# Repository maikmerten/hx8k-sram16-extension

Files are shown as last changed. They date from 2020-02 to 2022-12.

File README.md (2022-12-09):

# hx8k-sram16-extension
A PCB with 4 Mbit of SRAM,  SPI-Flash, two LEDs, a button, SPI-connectors, and a single-row pmod-compatible connector for the Lattice HX8K Breakout Board. Connects to the headers **J3** and **J4** on the Lattice HX8K Breakout Board.

## WARNING: unstable

The board in its current state is difficult to operate in a stable manner. While signals to the SRAM-chip appear to be of decent quality, I've yet to achieve stable operation over extended periods of operation. This might be a matter of my SRAM-controller design within the FPGA, or an issue with the board design available here. Please be aware of this before considering deploying this design in your projects.

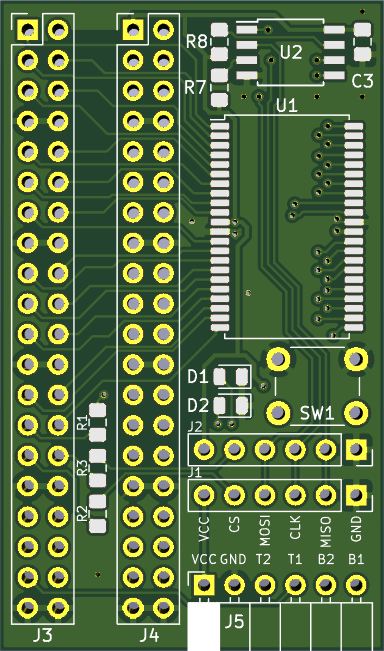
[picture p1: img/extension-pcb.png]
top side of the board top side


## BOM

| Component | Description | Qty. |
|---|---|---|
| U1 | 4 MBit SRAM chip, 256Kx16, e.g. AS7C34098A, 10ns or faster recommended, TSOP-II 44 package | 1 |
| U2 | SPI-Flash, e.g. W25Q32JV, 8-Pin SOIC package| 1 |
| C1, C2, C3 | 100nF ceramic capacitor, 0805 package | 3 |
| D1, D2 | SMD LEDs, red, 0805 package | 2 |
| R1, R2, R3, R4, R5, R6, R7, R8 | resistors, 1K, 0805 package | 8 |
| R9 | optional pull-up for SW1, anything between 10K and 50K should be fine, 0805 package | 1 |
| R10, R11 | resistors for the LEDs, 510 Ohm, 0805 package (**important:** populate before J3 and J4, as R10 and R11 will become inaccessible) | 2 |
| SW1 | 6x6 mm push button, THT | 1 |
| J1, J2 | 1x6 female header, 2.54 mm pin spacing | 2 |
| J3, J4 | 2x20 male pin headers, 2.54 mm pin spacing (**important:** solder on top side, so pins head downwards towards FPGA board)| 2 |
| J5 | 1x6 female right-angled header, 2.54 mm pin spacing | 1 |

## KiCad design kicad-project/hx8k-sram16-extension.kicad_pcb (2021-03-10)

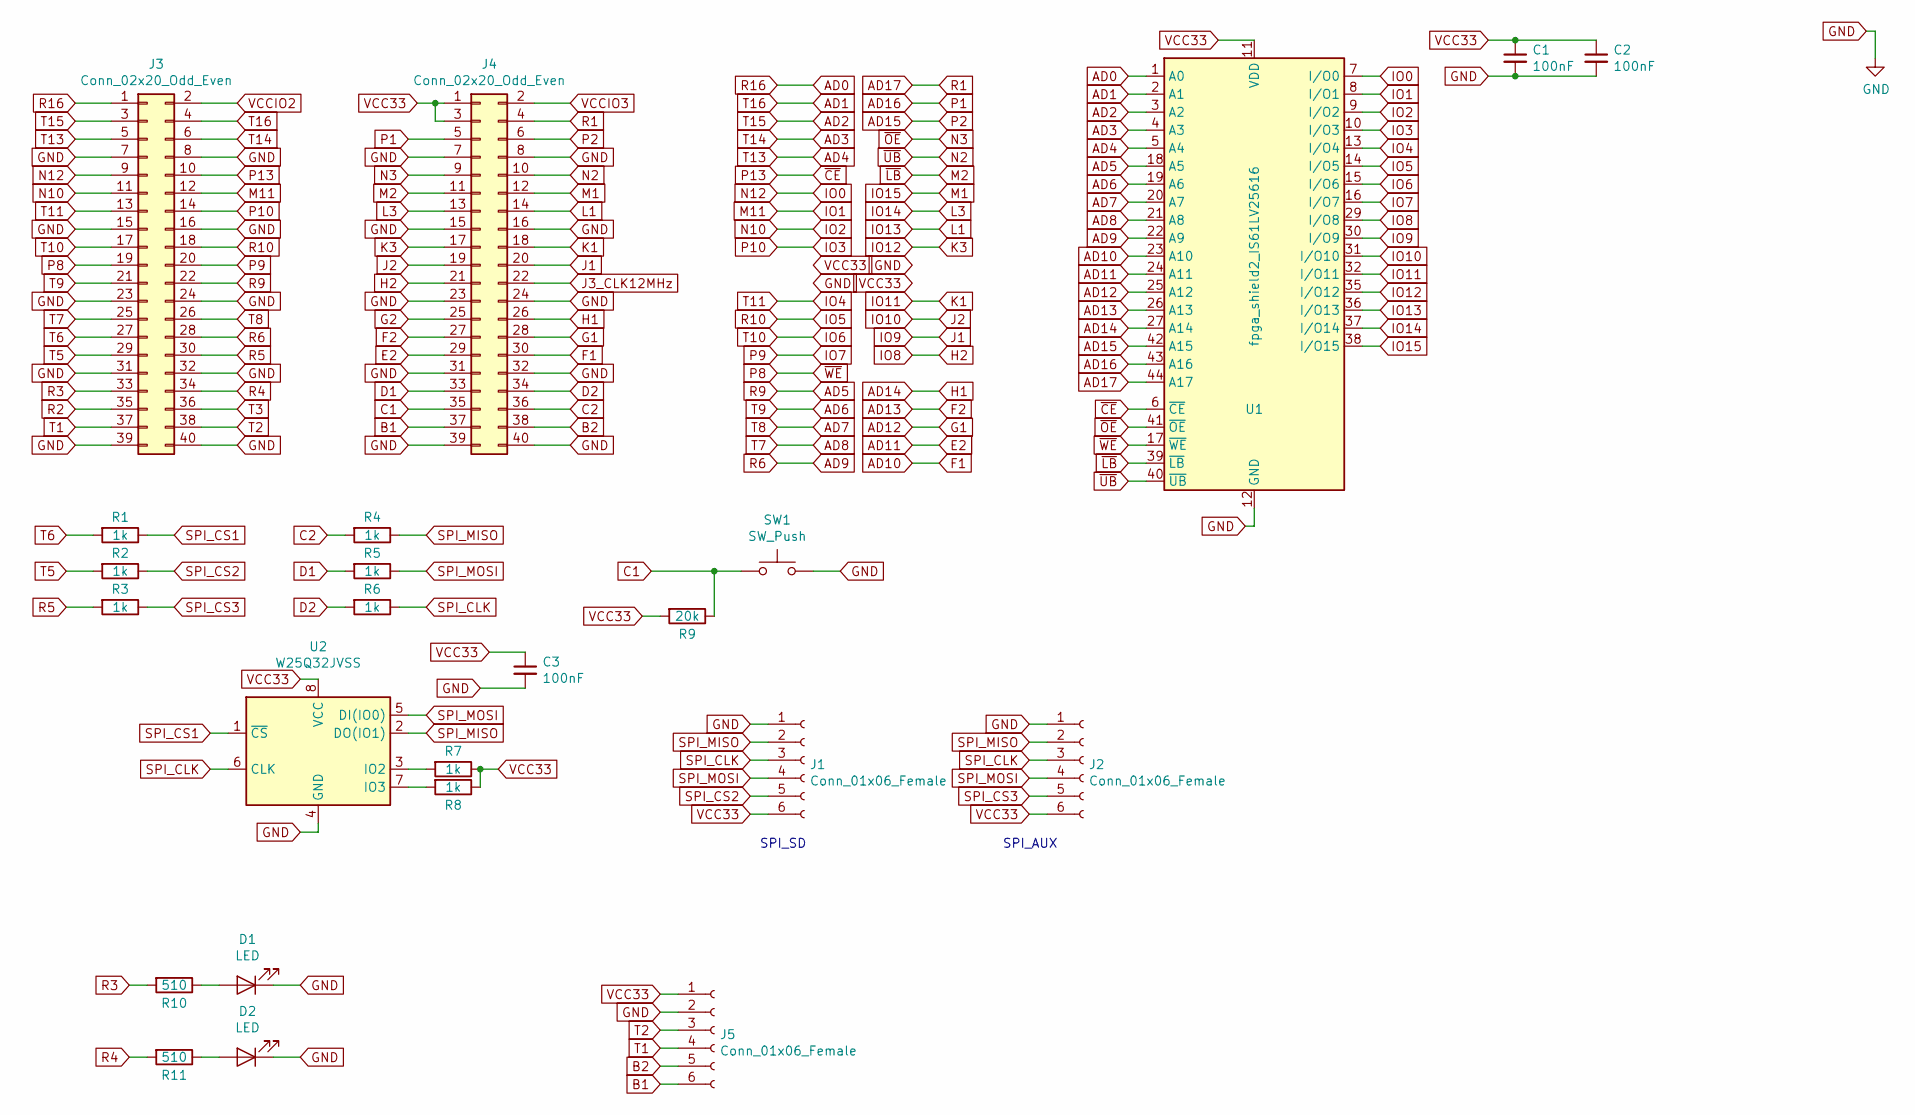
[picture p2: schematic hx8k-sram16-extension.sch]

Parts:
C1, C2, C3: 100nF; C_0805_2012Metric_Pad1.15x1.40mm_HandSolder
D1, D2: LED; LED_0805_2012Metric
J1, J2: Conn_01x06_Female; PinSocket_1x06_P2.54mm_Vertical
J3, J4: Conn_02x20_Odd_Even; PinHeader_2x20_P2.54mm_Vertical
J5: Conn_01x06_Female; PinSocket_1x06_P2.54mm_Horizontal
R1, R2, R3, R4, R5, R6, R7, R8: 1k; C_0805_2012Metric_Pad1.15x1.40mm_HandSolder
R9: 20k; C_0805_2012Metric_Pad1.15x1.40mm_HandSolder
R10, R11: 510; C_0805_2012Metric_Pad1.15x1.40mm_HandSolder
SW1: SW_Push; SW_PUSH_6mm
U1: fpga_shield2_IS61LV25616; TSOP-II-44_10.16x18.41mm_P0.8mm
U2: W25Q32JVSS; SOIJ-8_5.3x5.3mm_P1.27mm

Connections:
AD0: J3.1, U1.1 (A0)
AD1: J3.4, U1.2 (A1)
AD2: J3.3, U1.3 (A2)
AD3: J3.6, U1.4 (A3)
AD4: J3.5, U1.5 (A4)
AD5: J3.22, U1.18 (A5)
AD6: J3.21, U1.19 (A6)
AD7: J3.26, U1.20 (A7)
AD8: J3.25, U1.21 (A8)
AD9: J3.28, U1.22 (A9)
AD10: J4.30, U1.23 (A10)
AD11: J4.29, U1.24 (A11)
AD12: J4.28, U1.25 (A12)
AD13: J4.27, U1.26 (A13)
AD14: J4.26, U1.27 (A14)
AD15: J4.6, U1.42 (A15)
AD16: J4.5, U1.43 (A16)
AD17: J4.4, U1.44 (A17)
B1: J4.37, J5.6
B2: J4.38, J5.5
C1: J4.35, R9.1, SW1.1
C2: J4.36, R4.2
D1: J4.33, R5.2
D2: J4.34, R6.2
G2: J4.25
GND: C1.2, C2.2, C3.2, D1.1 (K), D2.1 (K), J1.1, J2.1, J3.7, J3.8, J3.15, J3.16, J3.23, J3.24, J3.31, J3.32, J3.39, J3.40, J4.7, J4.8, J4.15, J4.16, J4.23, J4.24, J4.31, J4.32, J4.39, J4.40, J5.2, SW1.2, U1.12 (GND), U1.34 (GND), U2.4 (GND)
H2: J4.21, U1.29 (I/O8)
IO0: J3.9, U1.7 (I/O0)
IO1: J3.12, U1.8 (I/O1)
IO2: J3.11, U1.9 (I/O2)
IO3: J3.14, U1.10 (I/O3)
IO4: J3.13, U1.13 (I/O4)
IO5: J3.18, U1.14 (I/O5)
IO6: J3.17, U1.15 (I/O6)
IO7: J3.20, U1.16 (I/O7)
IO9: J4.20, U1.30 (I/O9)
IO10: J4.19, U1.31 (I/O10)
IO11: J4.18, U1.32 (I/O11)
IO12: J4.17, U1.35 (I/O12)
IO13: J4.14, U1.36 (I/O13)
IO14: J4.13, U1.37 (I/O14)
IO15: J4.12, U1.38 (I/O15)
J3_CLK12MHz: J4.22
M2: J4.11, U1.39 (~LB)
N2: J4.10, U1.40 (~UB)
N3: J4.9, U1.41 (~OE)
unnamed: D1.2 (A), R10.1
unnamed: D2.2 (A), R11.1
unnamed: R7.2, U2.3 (IO2)
unnamed: R8.2, U2.7 (IO3)
P8: J3.19, U1.17 (~WE)
P13: J3.10, U1.6 (~CE)
R2: J3.35
R3: J3.33, R10.2
R4: J3.34, R11.2
R5: J3.30, R3.2
SPI_CLK: J1.3, J2.3, R6.1, U2.6 (CLK)
SPI_CS1: R1.1, U2.1 (~CS)
SPI_CS2: J1.5, R2.1
SPI_CS3: J2.5, R3.1
SPI_MISO: J1.2, J2.2, R4.1, U2.2 (DO(IO1))
SPI_MOSI: J1.4, J2.4, R5.1, U2.5 (DI(IO0))
T1: J3.37, J5.4
T2: J3.38, J5.3
T3: J3.36
T5: J3.29, R2.2
T6: J3.27, R1.2
VCC33: C1.1, C2.1, C3.1, J1.6, J2.6, J4.1, J4.3, J5.1, R7.1, R8.1, R9.2, U1.11 (VDD), U1.33 (VDD), U2.8 (VCC)
VCCIO2: J3.2
VCCIO3: J4.2

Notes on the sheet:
SPI_SD
SPI_AUX

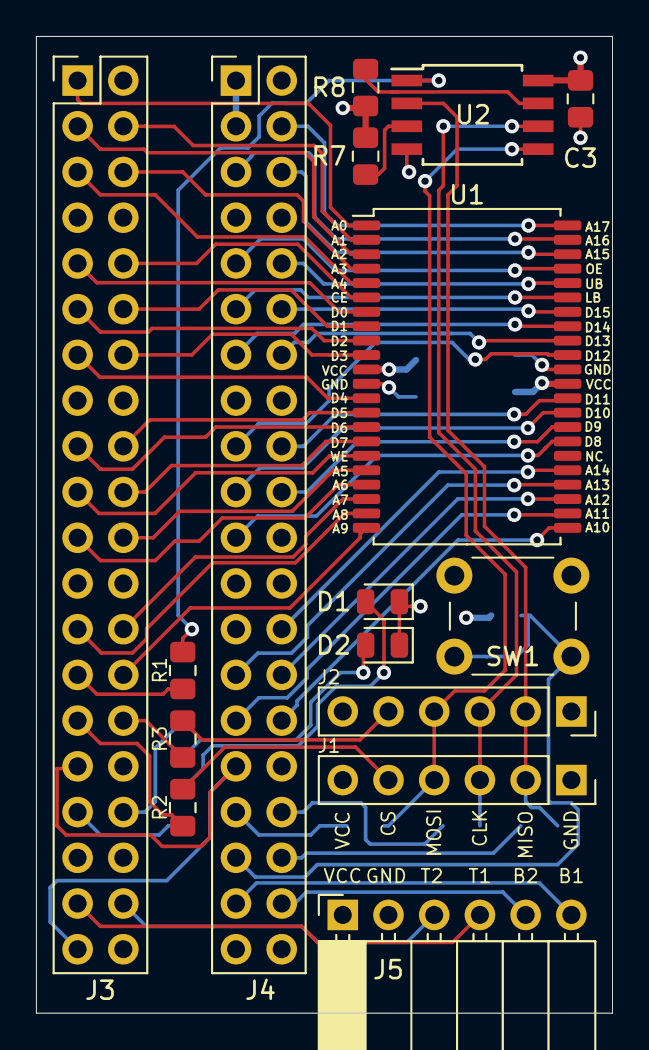
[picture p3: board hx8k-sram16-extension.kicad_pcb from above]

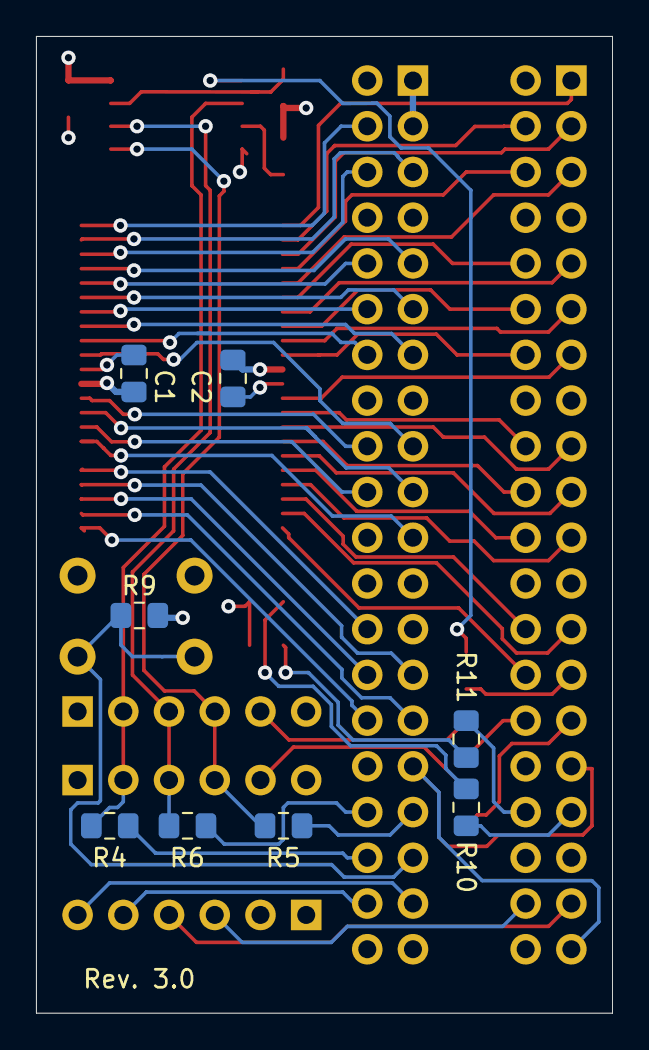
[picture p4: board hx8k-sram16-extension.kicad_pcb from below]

Board: 4 copper layers, 32.0 x 54.3 mm, 24 parts (8 on the bottom side), 64 nets.

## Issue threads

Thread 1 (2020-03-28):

Optimize pin use for FPGA banks?

rattboi, 2020-03-28:
Hi,

This is a really cool design! I am planning to use a portiona of it (the SRAM bits) and I was wondering if you had thought at all about how the IO use maps to the FPGA IO banks? I was considering have all address + control lines on one bank with the data lines on another to help the place+route optimize a bit better. Does that make any sense?

maikmerten, 2020-03-29:
Hi, thanks for your interest in the design!

I think it is possible to achieve better timing characteristics by keeping bank assignments in mind, although I guess that timing skew between banks is not necessarily a big concern compared to the PCB traces, depending on the quality of the place and route. This is just a hunch on my part, though.

In the current design I needed to work within the fixed layout of Lattice's HX8K Breakout Board and tried to keep the traces on the extension PCB as short as possible, as I assume that the timing delay introduced by the combined trace length (Breakout Board + connector + extension) would be bigger than whatever delay can be expected within the FPGA. Again, this is just a hunch, not backed up by any data.

However, if you design a new PCB with the FPGA and the SRAM on one board, then it certainly cannot hurt to keep bank assignments in mind.

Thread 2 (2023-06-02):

[Question] Dimensions

saahm, 2023-06-02:
Hi, thanks for this and your other repository that offer these neat extension boards.
I wanted to roll my own HX8K breakout board extension and figured out the dimensions on the board a wildly mixed (inch and mm, plus sometimes there is no obvious reference by which some parts are placed there).
When I checked both your board designs I see that once the pin header are apart by 9.2128 mm and once by 9 mm for the same measurement.
I currently can't accurately measure my ICE40HX8K-B-EVN board, but my estimate says 9.2128 is more correct, as 9 mm would be too little for that measurement.

I'm glad about your repos tho, it's the only available board for that breakout board I found so far that provide some useful references.

I wanted to roll a board with all 4 headers on an extension board if possible, but from the breakout board itself I cant really figure out proper dimensions so far. Pretty undocumented, which is why your repos are an oasis in that regard :100:

I thought to maybe bounce a few ideas here while asking that if you dont mind.

maikmerten, 2023-06-03:
Yeah, the dimensions are somewhat "educated guesses" I made by crudely measuring my physical ICE40 boards, as I didn't find the original design files. The finished boards thankfully fit without needing persuasion - there's enough wiggle room in there. I accomplish this by inserting the header pins into the reference board, then putting the extension board on top and *then* soldering the headers into the extension board. This way sub-millimeter precision isn't crucial.

Between "hx8k-breakout-extension"  and "hx8k-sram16-extension", I'd assume the latter is more precise, as its a newer design.

Feel free to proceed with the designs as you see fit!

saahm, 2023-06-05:
Ah, ok that explains a lot :)
Thanks, so I will orient on your latest version.

Closed 2023-06-05.

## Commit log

2020-02-15 commit project files
    [hx8k-sram16-extension.kicad_pcb, hx8k-sram16-extension.sch]
2020-02-15 add gerber files
2020-02-15 add a picture of the PCB
2021-03-10 switch to four layers
    [hx8k-sram16-extension.kicad_pcb]
2022-12-09 update README.md regarding board stability
